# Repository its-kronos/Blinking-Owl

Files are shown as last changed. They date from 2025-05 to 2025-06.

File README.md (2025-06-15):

# Blinking-Owl
An astable multivibrator with flashing LEDs that serve as eyes for an owl.

# Schematic


# PCB

## Front





## Back





# BOM

- (2) CR2032 Battery Cell Holders
- (8) 4.7k Ohm Resistors
- (4) 47k Ohm Resistors
- (2) 10 uF Capacitors
- (2) LEDs
- (2) PNP Transistors

# Afterword
- After receiving the parts for the Hackclub "Solder" program, I was surprised that there were (12) 220 ohm resistors and (6) of the 4.7K and 47K ohm resisters, which wasn't explicitly made clear. This taught me that it's always a good idea to double check the available materials to avoid requiring substitutions.
- After ordering the PCB, the parts came around five days later. When I build a prototype on a breadboard, the LEDs wouldn't light up with 5 volts in series, but would only work in parallel, contrary to what a simulation on Falstad showed me. This taught me that it is often better to wire voltage-dependant things in parallel to avoid issues like these. It also helped to understand that even if it takes longer for a build to be completed, prototyping something in real life on something like a breadboard is important to make sure that there are no problems down the road.
- I still figured out a way to make the current PCB work out with the current wiring, which was by adding two wires to connect corresponding legs of the two LEDs while scratching out the currect trace that connected them. Keeping this trace would allow current to flow backwards in an unintended direction to directly go through wires or traces, keeping the LEDs unlit.

# Demonstrations

## Prototype
https://vimeo.com/1090699929/9bd934338b?share=copy

## Assembly
https://vimeo.com/1093416475/6044e68823?share=copy

# Attributions
\- Created by its_kronos

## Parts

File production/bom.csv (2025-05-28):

Designator | Footprint | Quantity | Value | LCSC Part #
BT1, BT2 | BatteryHolder_Keystone_3034_1x20mm | 2 | 3V cr2032
C1, C2 | CP_Radial_D8.0mm_P5.00mm | 2 | 10uF
D1, D2 | LED_D5.0mm | 2 | LED
Q1, Q2 | TO-92L_HandSolder | 2 | PNP
R1, R12, R2, R3, R4, R5, R6, R7 | R_Axial_DIN0207_L6.3mm_D2.5mm_P7.62mm_Horizontal | 8 | 4.7k
R10, R11, R8, R9 | R_Axial_DIN0207_L6.3mm_D2.5mm_P7.62mm_Horizontal | 4 | 47k

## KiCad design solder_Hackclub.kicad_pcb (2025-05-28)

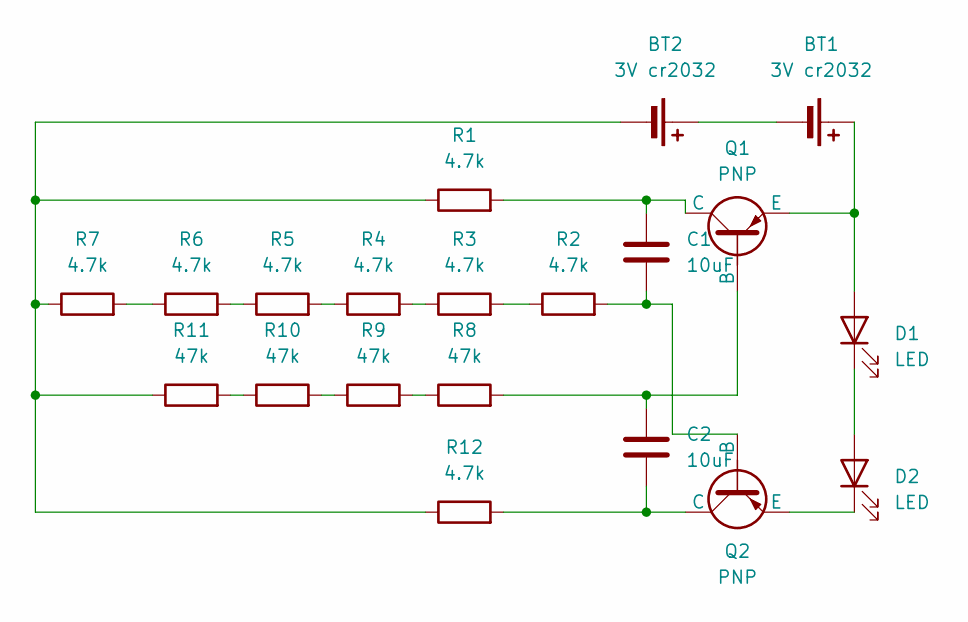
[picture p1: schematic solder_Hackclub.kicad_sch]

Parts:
BT1, BT2: 3V cr2032; BatteryHolder_Keystone_3034_1x20mm
C1, C2: 10uF; CP_Radial_D8.0mm_P5.00mm
D1, D2: LED; LED_D5.0mm
Q1, Q2: PNP; TO-92L_HandSolder
R1, R2, R3, R4, R5, R6, R7, R12: 4.7k; R_Axial_DIN0207_L6.3mm_D2.5mm_P7.62mm_Horizontal
R8, R9, R10, R11: 47k; R_Axial_DIN0207_L6.3mm_D2.5mm_P7.62mm_Horizontal

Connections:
unnamed: BT1.1 (+), D1.2 (A), Q1.3 (E)
unnamed: BT1.2 (-), BT2.1 (+)
unnamed: BT2.2 (-), R1.1, R7.1, R11.1, R12.1
unnamed: D1.1 (K), D2.2 (A)
unnamed: D2.1 (K), Q2.3 (E)
unnamed: C2.1, Q1.2 (B), R8.2
unnamed: C1.1, Q1.1 (C), R1.2
unnamed: C1.2, Q2.2 (B), R2.2
unnamed: C2.2, Q2.1 (C), R12.2
unnamed: R2.1, R3.2
unnamed: R3.1, R4.2
unnamed: R4.1, R5.2
unnamed: R5.1, R6.2
unnamed: R6.1, R7.2
unnamed: R8.1, R9.2
unnamed: R10.1, R11.2
unnamed: R9.1, R10.2

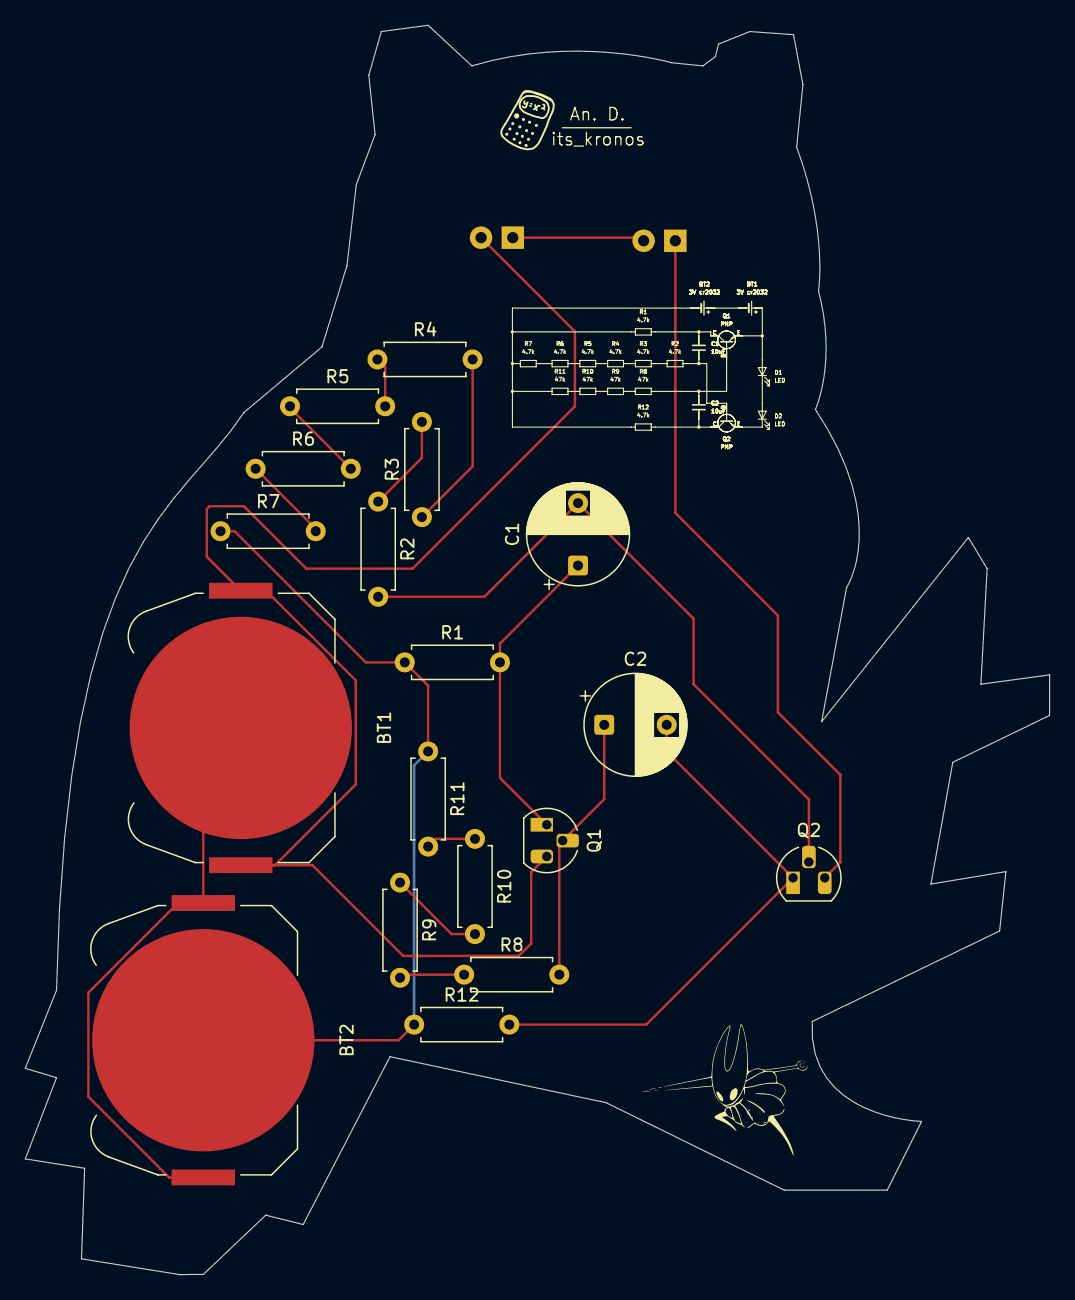
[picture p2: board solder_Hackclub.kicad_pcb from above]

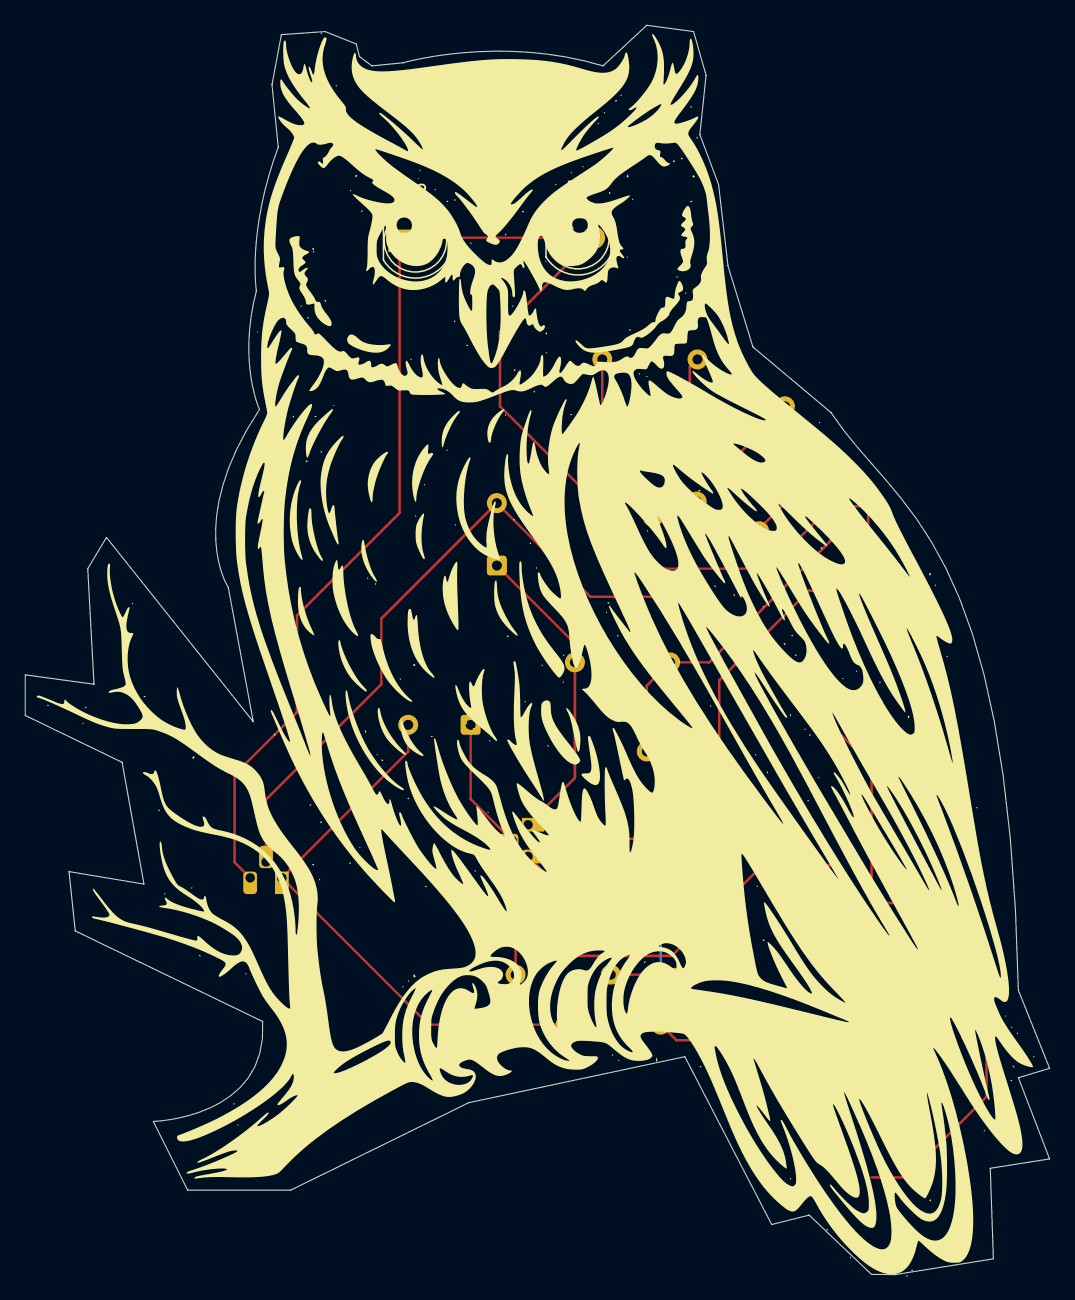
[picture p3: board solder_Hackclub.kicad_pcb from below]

Board: 2 copper layers, 82.0 x 100.0 mm, 20 parts (2 on the bottom side), 17 nets.

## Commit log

2025-05-28 Add folders
    [bom.csv, designators.csv, positions.csv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]
2025-06-15 Update README.md - add assembly video
